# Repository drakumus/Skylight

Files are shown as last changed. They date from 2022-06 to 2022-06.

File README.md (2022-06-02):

# About
This is Skylight, a numpad with two rotary encoders using ATMEGA32a-PU Microcontroller.

# Project Details
## case
`case` the files used to laser cut my case out of acrylic and stainless steel. SendCutSend was a responsive and friendly service I used with reasonable prices, so I'd recommend contacting them.
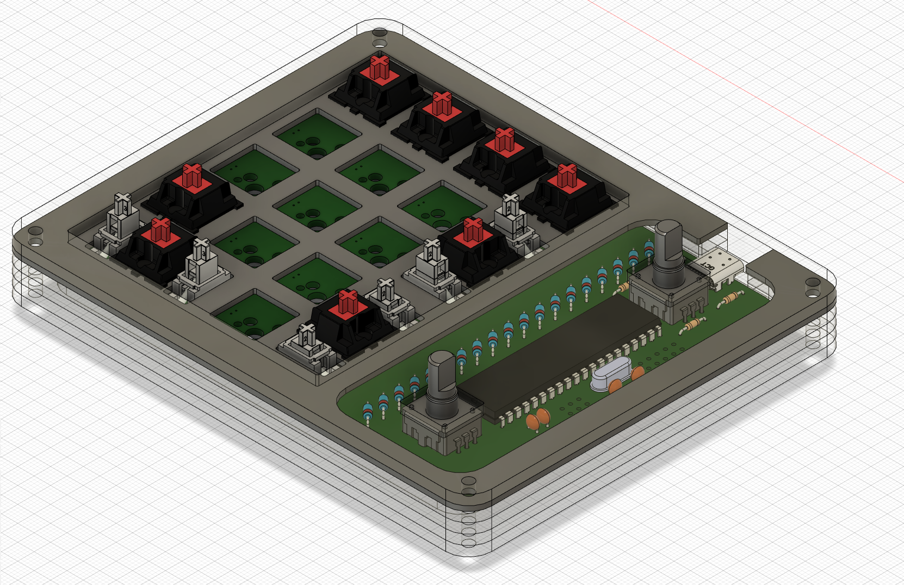
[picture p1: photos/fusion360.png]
case

### Files Required for Fabrication:
```
x1	bottom plate (closed).dxf 	- 3mm acrylic
x1	bottom plate (no usb).dxf 	- 3mm acrylic
x2	bottom plate.dxf		- 3mm acrylic
x1	plate.dxf			- stainless steel, ideal 1.5mm
x1	top plate v2.dxf		- 3mm acrylic
```
### Other Files
Other files can either be used for modeling i.e. the base.step which is a 3d render of the pcb for case design, or are previous iterations of files that I kept for future reference.
## USBaspLoader (bootloader)
ATMEGA32A-PU does not come with native USB support. A bootloader with VUSB support must be flashed to let QMK Toolbox recognize the device for flashing via USBasp. This is achieved with USBaspLoader.
I've included my confuration of the loader with instructions to use below.

**NOTE:** Flashing on windows requires avrdude. The sourceforge version of Avrdude that I will not link to **DELETES YOUR PATH ENVIRONMENT VARIABLE**. I did this twice on two different installs of windows before figuring it out. I hope you find a better way to install. You may have better luck with choco package manager for windows but the current version on there is 6.3 which requires custom drivers you must place manually in your system32 folder. The other option is WSL however I believe there are still limitations for that to see COM ports. I hope the future has a more dev friendly approach.
### Requirements
 - ISP (I repurposed a Pro Micro to do this, [see qmk's guide](https://github.com/qmk/qmk_firmware/blob/master/docs/isp_flashing_guide.md))
 - Avrdude
 - Git Bash (other WSL consoles probably work)
### Loading the Bootloader
1. Open [QMK Toolbox](https://github.com/qmk/qmk_toolbox/releases)
2. Check what COM port your ISP is plugged into (i.e. COM3)
3. Edit Makefile.inc (line 41) in the USBaspLoader folder with the correct COM port and the isp specified in the QMK guide above.
		i.e. `PROGRAMMER = -c avrisp -P COM3`
4. `cd` into my version of USBaspLoader with git bashs
5. Use git bash (has make tools we need) to execute:
  	1. make firmware
	2. avrdude -c avrisp -p m32 -P COM6 -v 
		- make sure the device number is not 0x00000, if it is double check the pin configuration on your ISP
	3. avrdude -c avrisp -p m32 -P COM6 -v -u -U lfuse:w:0x1F:m
	4. avrdude -c avrisp -p m32 -P COM6 -v -u -U hfuse:w:0xC0:m
	5. make flash
	6. avrdude -c avrisp -p m32 -P COM6 -U flash:r:-:i
		- this just reads the flash memory space to make sure the bits were set.

Congrats you now have a bootloader installed. You're now ready to flash your first firmware.
## firmware
**NOTE:** Do not attempt to flash the hex from qmk_firmware until after a bootloader has been flashed (found in USBaspLoader).

This folder contains the qmk firmware flashed to the board. Note that I flash the via supported kecap set.
If you want to play with this dump this folder into the keyboard folder in the qmk_firmware repository.
### Example build:
Open QMK MYSYS and run `qmk compile -kb zoci/skylight -km via` after dropping the zoci folder into the qmk_firmware/keyboard folder.
### Flashing the Board
1. In order to flash the two 2.54mm female "jumper" pins towards the right, top side of the board must be connected together. You can do this with tweezers or a wire.
2. Plug in the board via USB-C port on the device to USB-A on your computer.
3. QMK Toolbox should now detect the device (if the bootloader has been flashed previously)
4. Select the `zoci_skylight_via.hex` file in the firmware folder and click Flash.
5. Once it says flash complete disconnect the board from the computer then remove the connection between the two jumper pins.
6. Plug the board back into the computer.

You now have a functioning PCB!
### Via Support
> :warning: **Only use static RGB**: other color modes will cause the board to crash repeatedly forcing a reflash! This is likely because the microcontroller is too slow to continuously write rgb data.

In order for via to work with this board you must:
1. Go to the `SETTINGS` tab and toggle the "Show Design tab" to on.
2. Go to the `DESIGN` tab and select "LOAD" then open the via.json: `./firmware/zoci/skylight_s2/via.json`
3. Go to the `CONFIGURE` tab.
4. You may have to unplug and replug the board for it to show up. In general it is recommended to launch via then plug in the board.

You now can modify the button controls in via instead of building your own qmk hex!
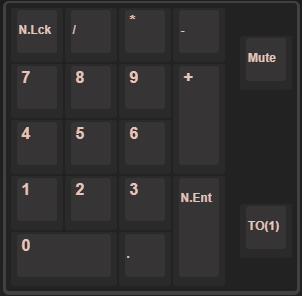
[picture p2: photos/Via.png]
Via

## kicad files
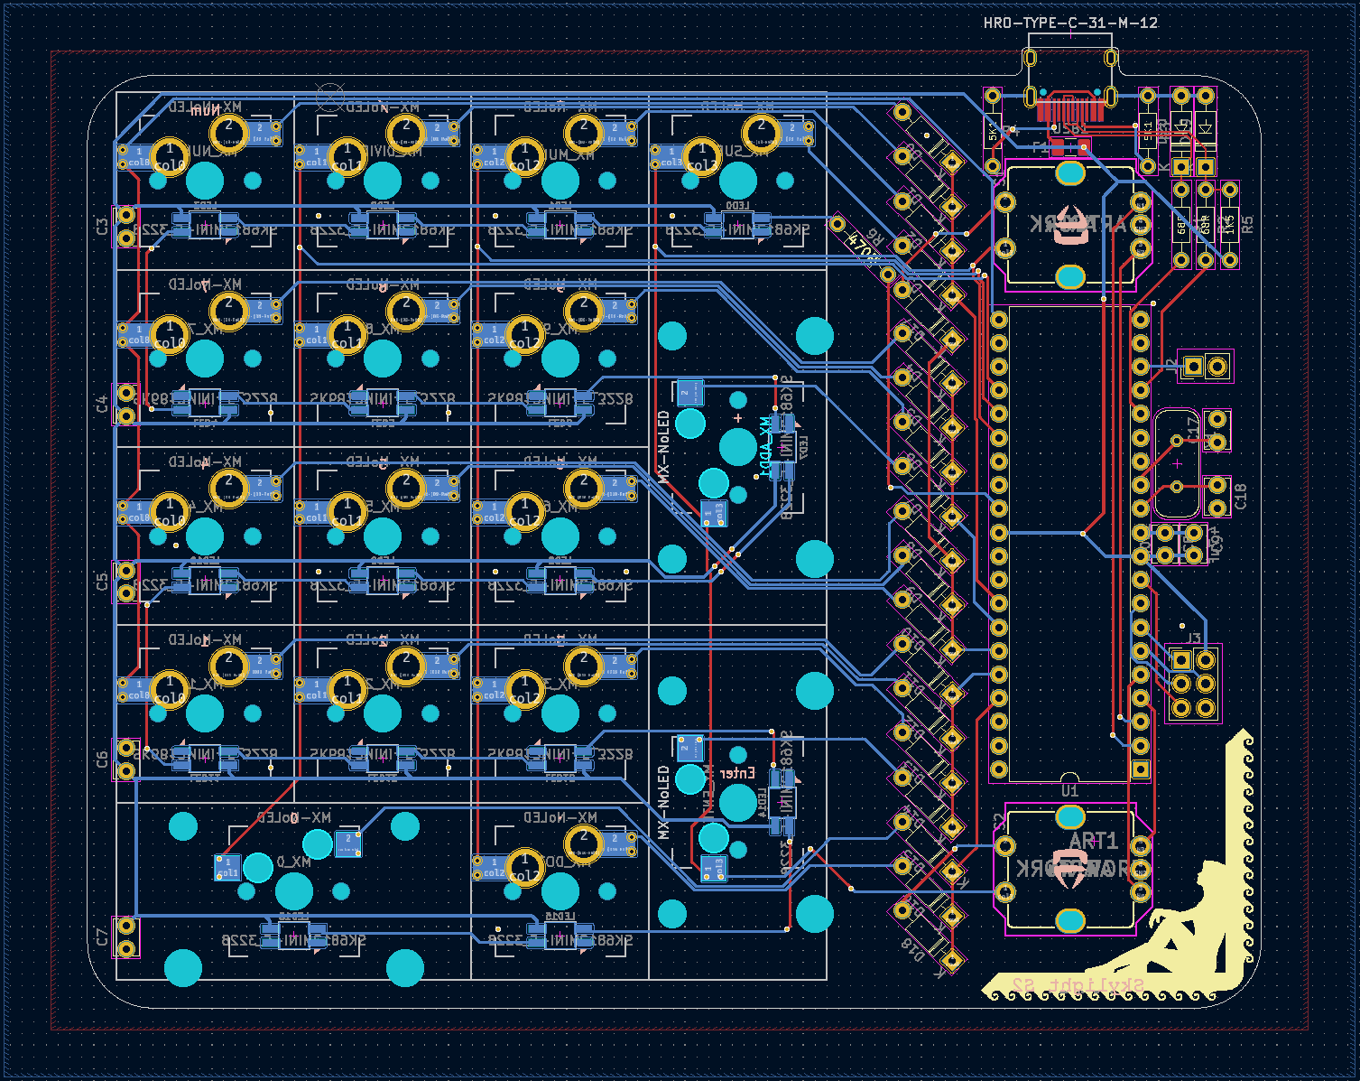
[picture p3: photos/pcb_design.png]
pcb

This folder contains the kicad project and its dependancies.
**Note:** You must clone recursively to get the submodule requirements for the kicad dependencies to load properly.
### Files Required for Fabrication
```
./Fabrication Files/plots final.zip
```

You can upload this file to a site like JLCPCB for fabrication.
### BOM
TODO

# Images

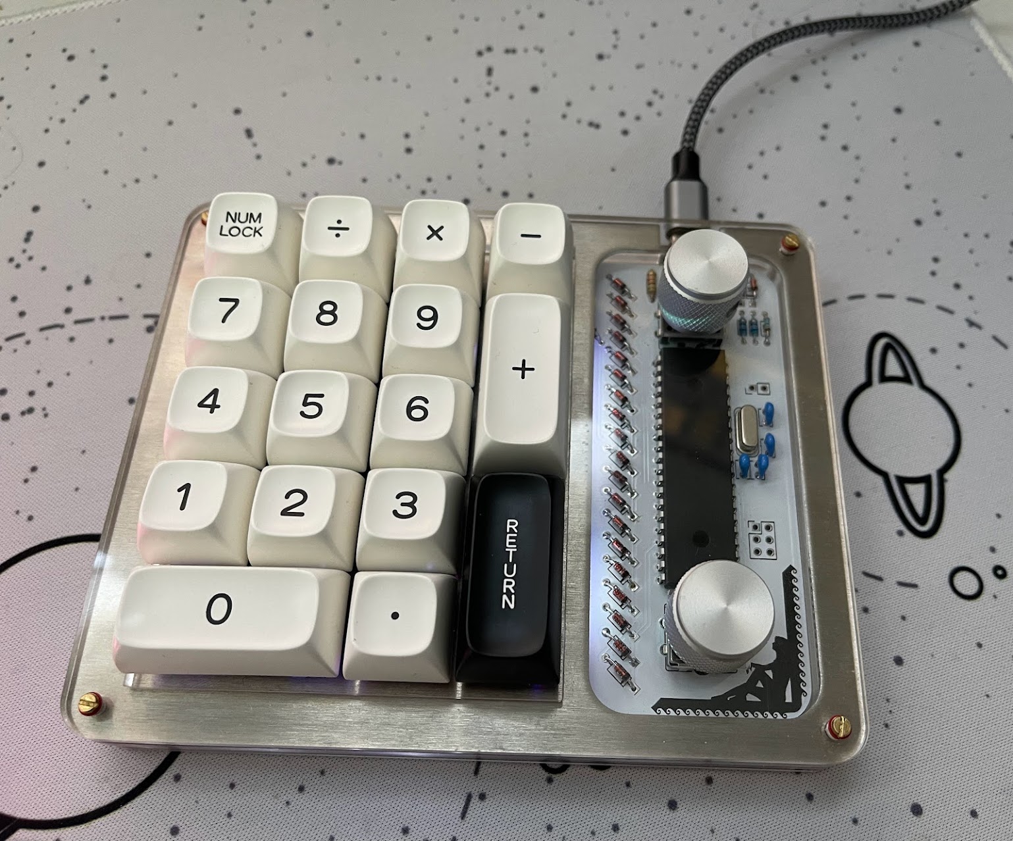
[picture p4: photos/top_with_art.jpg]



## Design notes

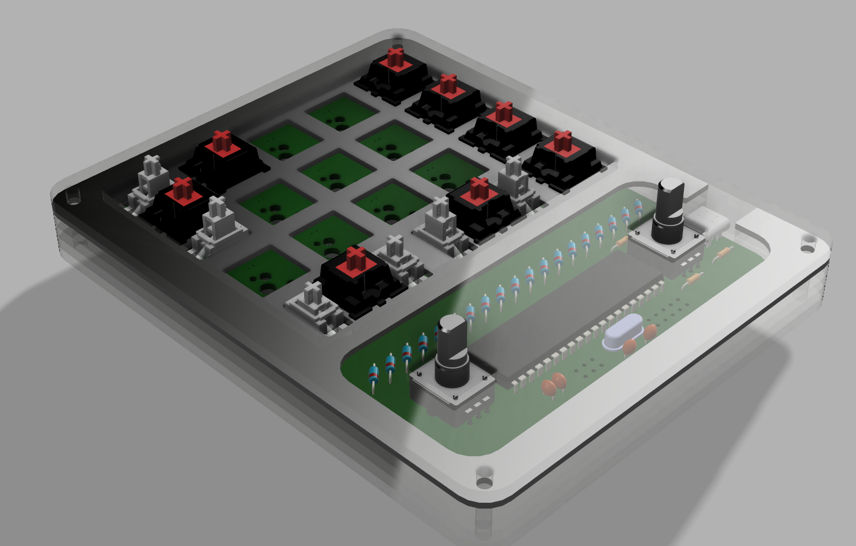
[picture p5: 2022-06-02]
photos/render.png

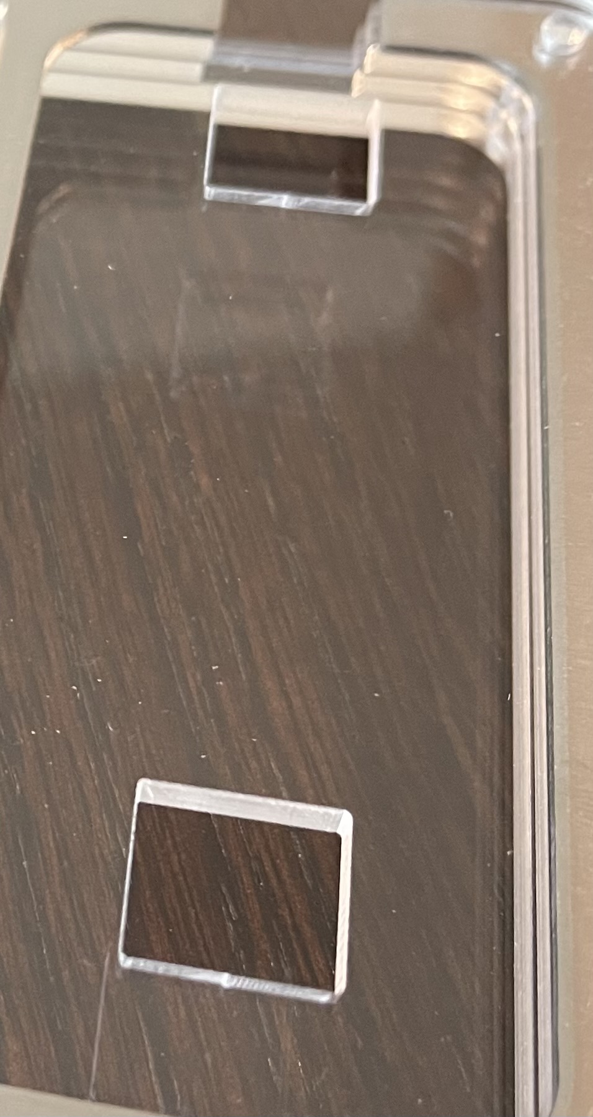
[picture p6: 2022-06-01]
case/bump.jpg

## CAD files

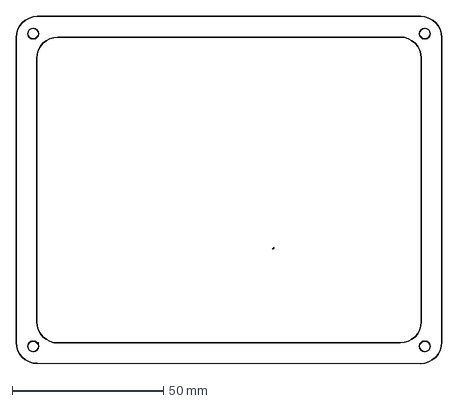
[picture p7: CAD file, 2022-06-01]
case/bottom plate (no usb).dxf
140.6 x 114.6 mm

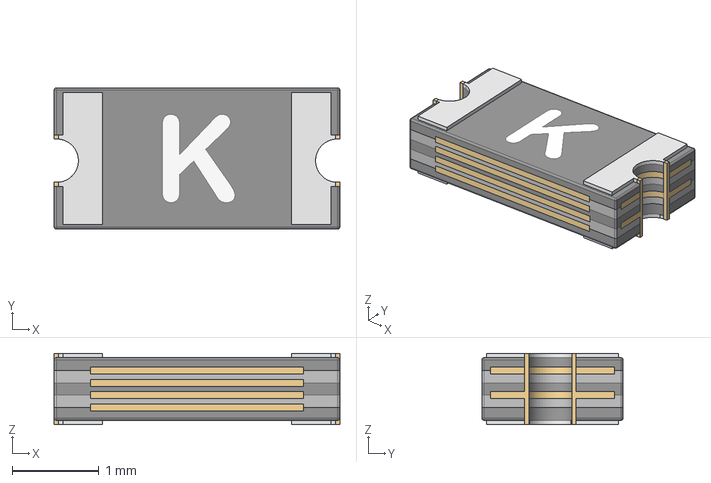
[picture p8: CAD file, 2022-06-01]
kicad files/components/smd-1206-fuse-littelfuse-1206l150thwr-1.snapshot.2/Fuse Littelfuse 1206L150THWR.stp
3.30 x 1.63 x 0.825 mm

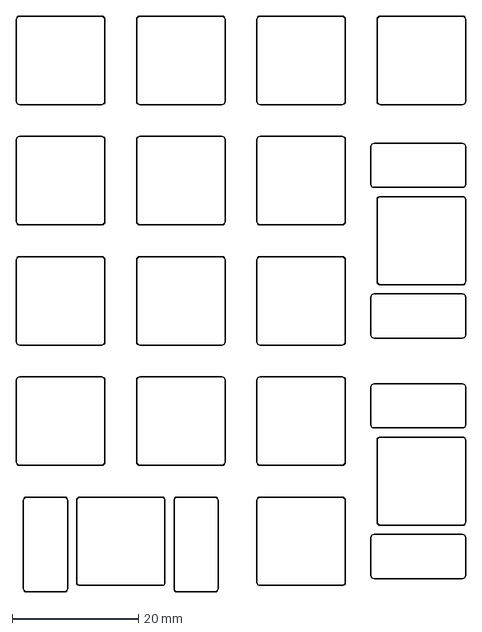
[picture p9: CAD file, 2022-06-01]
case/kbplate.dxf
71.1 x 91.2 mm

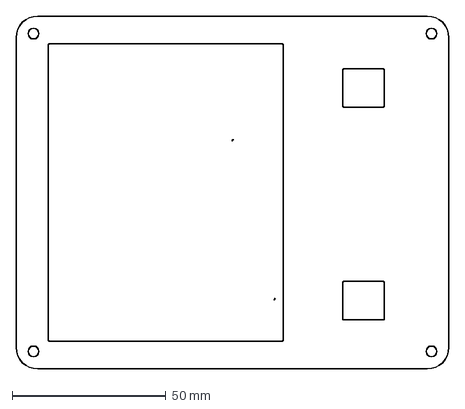
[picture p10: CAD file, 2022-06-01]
case/top plate.dxf
140.6 x 114.6 mm

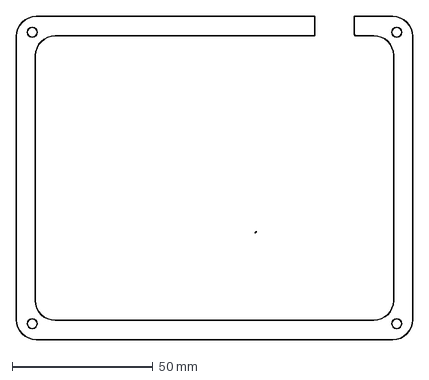
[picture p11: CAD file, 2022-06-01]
case/bottom plate.dxf
140.6 x 114.6 mm

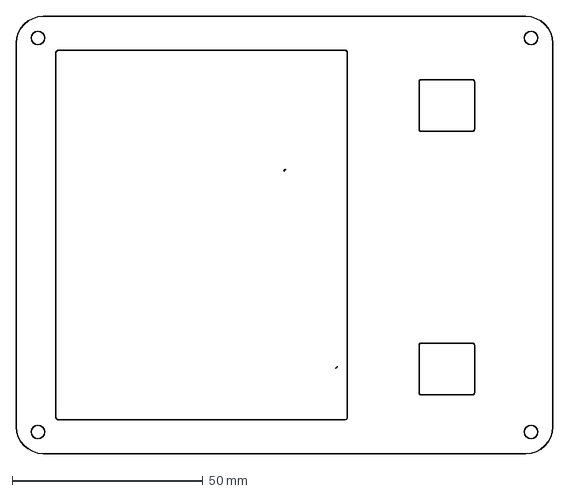
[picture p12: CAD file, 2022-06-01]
case/top plate v2.dxf
140.6 x 114.6 mm

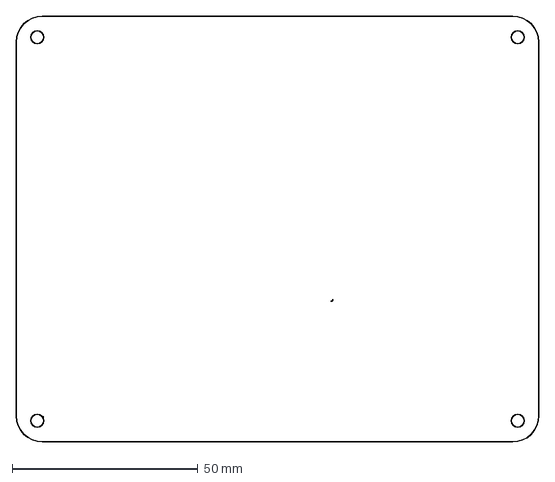
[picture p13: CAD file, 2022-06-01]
case/bottom plate (closed).dxf
140.6 x 114.6 mm

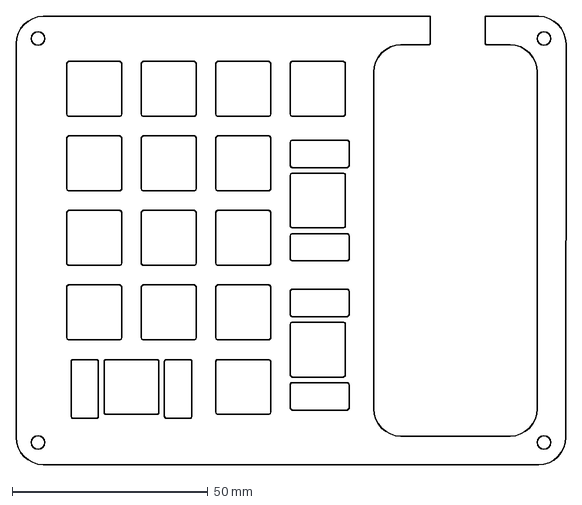
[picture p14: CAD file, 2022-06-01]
case/plate.dxf
140.6 x 114.6 mm

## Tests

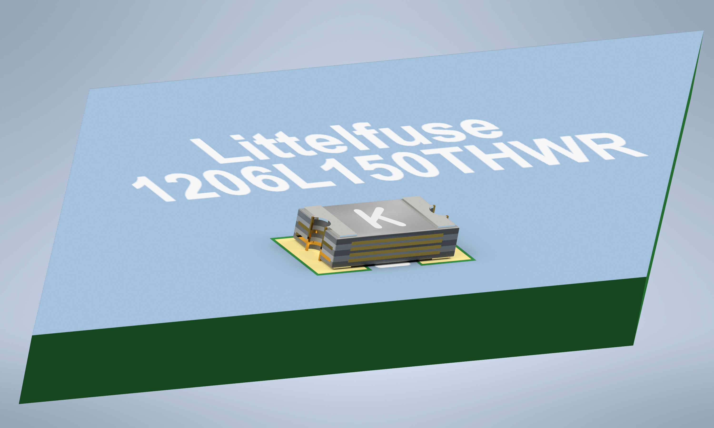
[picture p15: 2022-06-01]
kicad files/components/smd-1206-fuse-littelfuse-1206l150thwr-1.snapshot.2/Test.png

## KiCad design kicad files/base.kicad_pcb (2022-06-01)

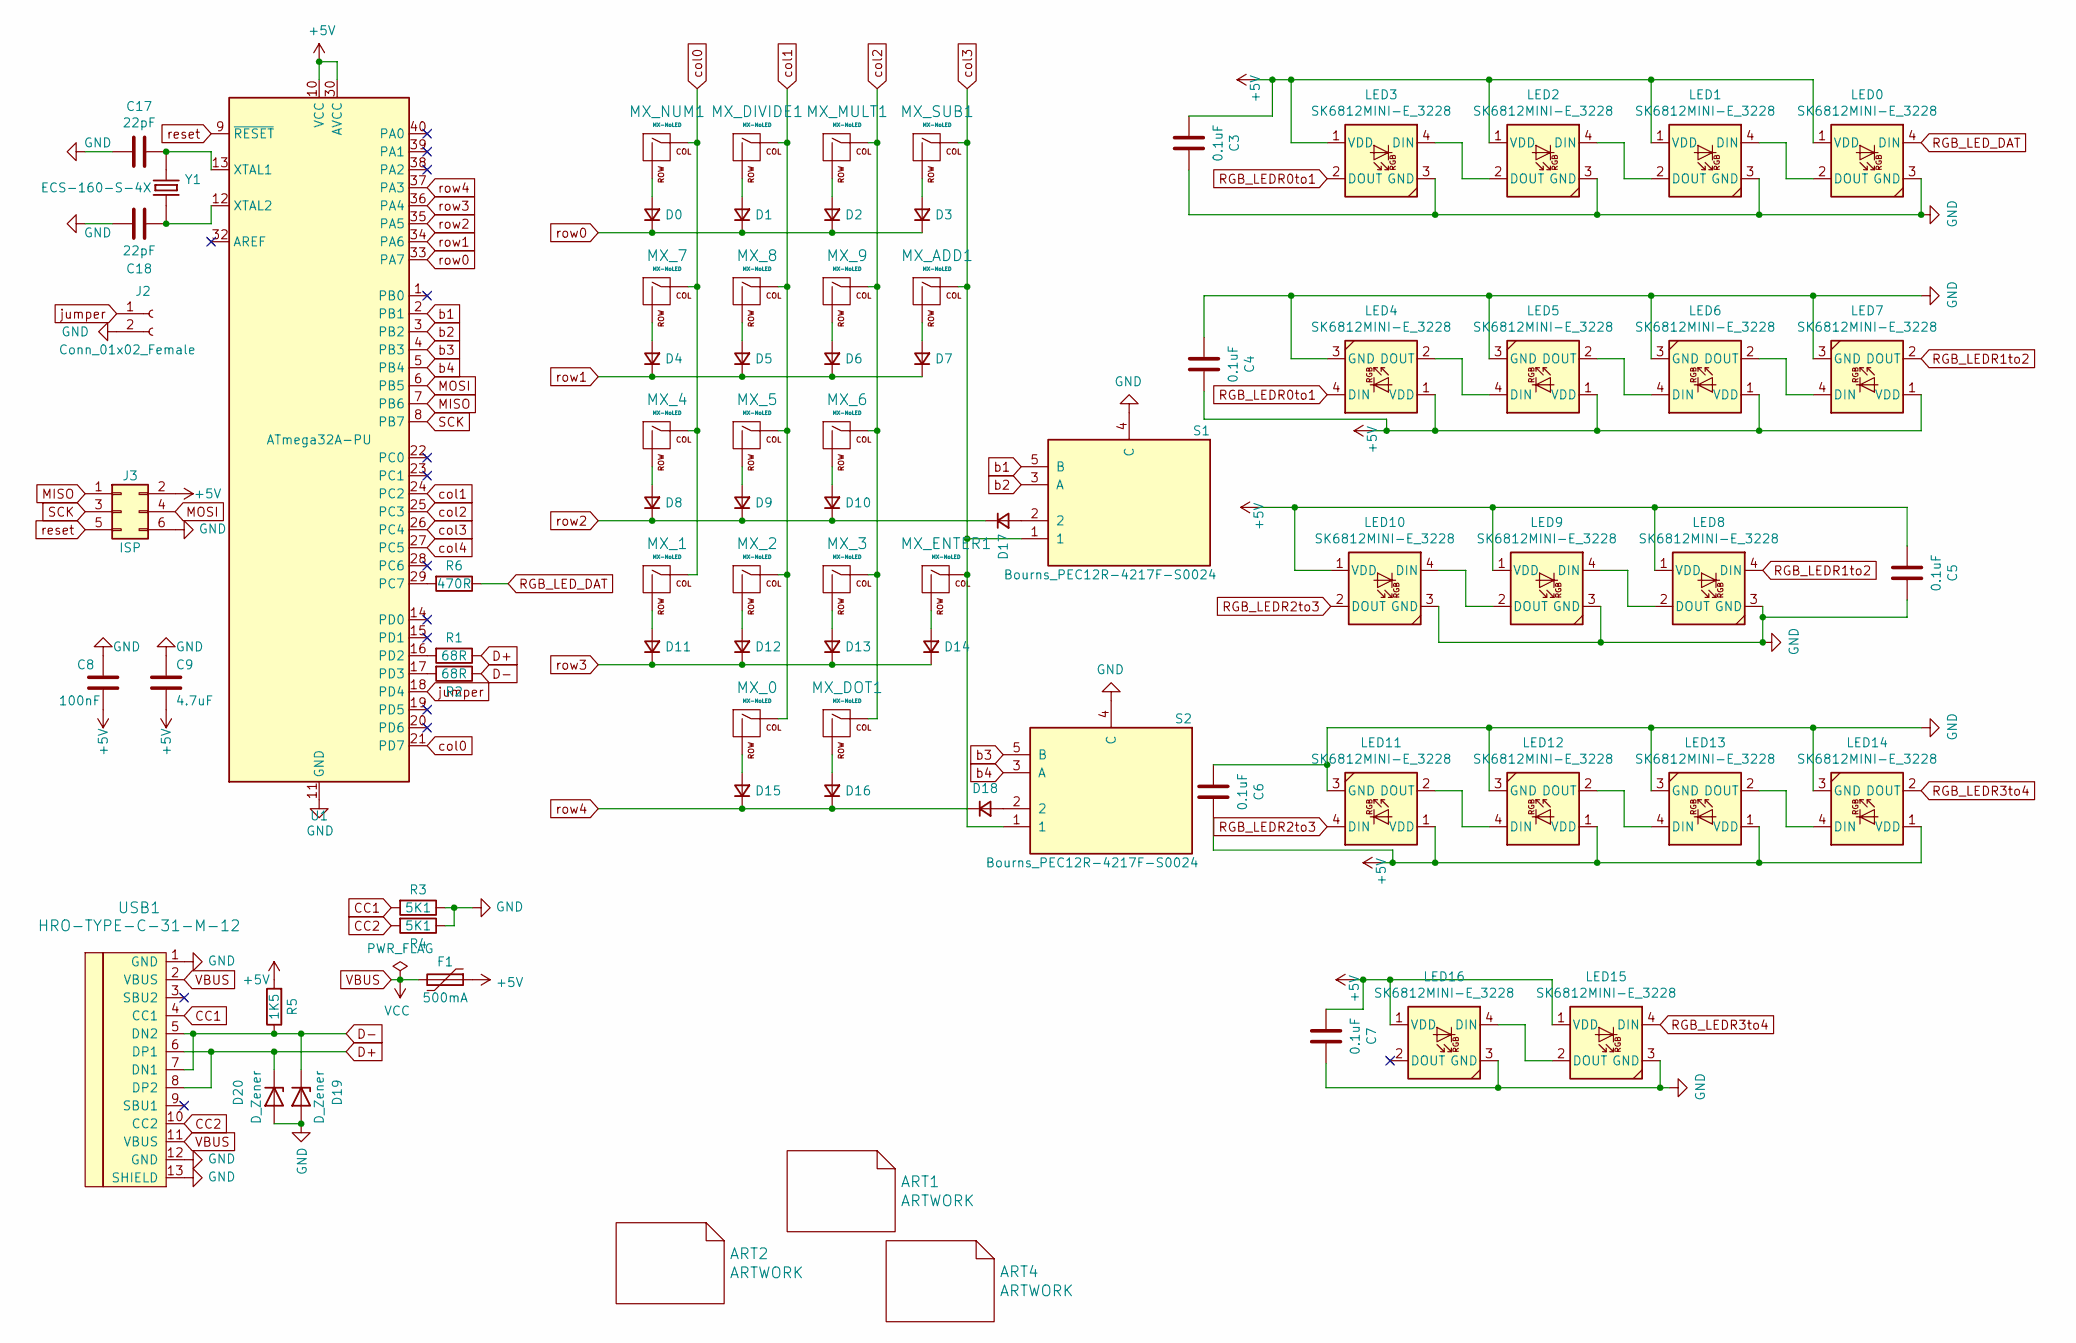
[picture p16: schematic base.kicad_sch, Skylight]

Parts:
ART1: ARTWORK; border and silhouette
ART2: ARTWORK; name
ART4: ARTWORK; avenda
C3, C4, C5, C6, C7: 0.1uF; C_Disc_D3.8mm_W2.6mm_P2.50mm
C8: 100nF; C_Disc_D3.8mm_W2.6mm_P2.50mm
C9: 4.7uF; C_Disc_D3.8mm_W2.6mm_P2.50mm
C17, C18: 22pF; C_Disc_D3.8mm_W2.6mm_P2.50mm
D0, D1, D2, D3, D4, D5, D6, D7, D8, D9, D10, D11, D12, D13, D14, D15, D16, D17, D18: D_Small; D_DO-35_SOD27_P7.62mm_Horizontal
D19, D20: D_Zener; D_DO-35_SOD27_P7.62mm_Horizontal
F1: 500mA; Fuse_1206_3216Metric
J2: Conn_01x02_Female; PinHeader_1x02_P2.54mm_Vertical
J3: ISP; PinHeader_2x03_P2.54mm_Vertical
LED0, LED1, LED2, LED3, LED4, LED5, LED6, LED7, LED8, LED9, LED10, LED11, LED12, LED13, LED14, LED15, LED16: SK6812MINI-E_3228; SK6812-MINI-E
MX_0: MX-NoLED; MXOnly-2U-Hotswap
MX_1, MX_2, MX_3, MX_4, MX_5, MX_6, MX_7, MX_8, MX_9: MX-NoLED; MXOnly-1U-Hotswap-Antishear
MX_ADD1: MX-NoLED; MXOnly-2U-Hotswap
MX_DIVIDE1: MX-NoLED; MXOnly-1U-Hotswap-Antishear
MX_DOT1: MX-NoLED; MXOnly-1U-Hotswap-Antishear
MX_ENTER1: MX-NoLED; MXOnly-2U-Hotswap
MX_MULT1: MX-NoLED; MXOnly-1U-Hotswap-Antishear
MX_NUM1: MX-NoLED; MXOnly-1U-Hotswap-Antishear
MX_SUB1: MX-NoLED; MXOnly-1U-Hotswap-Antishear
R1, R2: 68R; R_Axial_DIN0204_L3.6mm_D1.6mm_P7.62mm_Horizontal
R3, R4: 5K1; R_Axial_DIN0204_L3.6mm_D1.6mm_P7.62mm_Horizontal
R5: 1K5; R_Axial_DIN0204_L3.6mm_D1.6mm_P7.62mm_Horizontal
R6: 470R; R_Axial_DIN0204_L3.6mm_D1.6mm_P7.62mm_Horizontal
S1, S2: Bourns_PEC12R-4217F-S0024; PEC12R-4xxF-Sxxxx
U1: ATmega32A-PU; DIP-40_W15.24mm
USB1: HRO-TYPE-C-31-M-12; HRO-TYPE-C-31-M-12-HandSoldering
Y1: ECS-160-S-4X; XTAL_ECS-160-S-4X

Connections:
+5V: C3.2, C4.1, C5.2, C6.1, C7.2, C8.2, C9.2, F1.1, J3.2, LED0.1 (VDD), LED1.1 (VDD), LED2.1 (VDD), LED3.1 (VDD), LED4.1 (VDD), LED5.1 (VDD), LED6.1 (VDD), LED7.1 (VDD), LED8.1 (VDD), LED9.1 (VDD), LED10.1 (VDD), LED11.1 (VDD), LED12.1 (VDD), LED13.1 (VDD), LED14.1 (VDD), LED15.1 (VDD), LED16.1 (VDD), R5.2, U1.10 (VCC), U1.30 (AVCC)
CC1: R3.2, USB1.4 (CC1)
CC2: R4.2, USB1.10 (CC2)
D+: D20.1 (K), R1.1, USB1.6 (DP1), USB1.8 (DP2)
D-: D19.1 (K), R2.1, R5.1, USB1.5 (DN2), USB1.7 (DN1)
GND: C3.1, C4.2, C5.1, C6.2, C7.1, C8.1, C9.1, C17.2, C18.2, D19.2 (A), D20.2 (A), J2.2, J3.6, LED0.3 (GND), LED1.3 (GND), LED2.3 (GND), LED3.3 (GND), LED4.3 (GND), LED5.3 (GND), LED6.3 (GND), LED7.3 (GND), LED8.3 (GND), LED9.3 (GND), LED10.3 (GND), LED11.3 (GND), LED12.3 (GND), LED13.3 (GND), LED14.3 (GND), LED15.3 (GND), LED16.3 (GND), R3.1, R4.1, S1.4 (C), S2.4 (C), U1.11 (GND), U1.31 (GND), USB1.1 (GND), USB1.12 (GND), USB1.13 (SHIELD)
MISO: J3.1, U1.7 (PB6)
MOSI: J3.4, U1.6 (PB5)
unnamed: C17.1, U1.13 (XTAL1), Y1.1
unnamed: C18.1, U1.12 (XTAL2), Y1.2
unnamed: D0.2 (A), MX_NUM1.2 (ROW)
unnamed: D1.2 (A), MX_DIVIDE1.2 (ROW)
unnamed: D2.2 (A), MX_MULT1.2 (ROW)
unnamed: D3.2 (A), MX_SUB1.2 (ROW)
unnamed: D4.2 (A), MX_7.2 (ROW)
unnamed: D5.2 (A), MX_8.2 (ROW)
unnamed: D6.2 (A), MX_9.2 (ROW)
unnamed: D7.2 (A), MX_ADD1.2 (ROW)
unnamed: D8.2 (A), MX_4.2 (ROW)
unnamed: D9.2 (A), MX_5.2 (ROW)
unnamed: D10.2 (A), MX_6.2 (ROW)
unnamed: D11.2 (A), MX_1.2 (ROW)
unnamed: D12.2 (A), MX_2.2 (ROW)
unnamed: D13.2 (A), MX_3.2 (ROW)
unnamed: D14.2 (A), MX_ENTER1.2 (ROW)
unnamed: D15.2 (A), MX_0.2 (ROW)
unnamed: D16.2 (A), MX_DOT1.2 (ROW)
unnamed: D17.2 (A), S1.2
unnamed: D18.2 (A), S2.2
unnamed: LED0.2 (DOUT), LED1.4 (DIN)
unnamed: LED1.2 (DOUT), LED2.4 (DIN)
unnamed: LED2.2 (DOUT), LED3.4 (DIN)
unnamed: LED4.2 (DOUT), LED5.4 (DIN)
unnamed: LED5.2 (DOUT), LED6.4 (DIN)
unnamed: LED6.2 (DOUT), LED7.4 (DIN)
unnamed: LED8.2 (DOUT), LED9.4 (DIN)
unnamed: LED9.2 (DOUT), LED10.4 (DIN)
unnamed: LED11.2 (DOUT), LED12.4 (DIN)
unnamed: LED12.2 (DOUT), LED13.4 (DIN)
unnamed: LED13.2 (DOUT), LED14.4 (DIN)
unnamed: LED15.2 (DOUT), LED16.4 (DIN)
unnamed: R1.2, U1.16 (PD2)
unnamed: R2.2, U1.17 (PD3)
unnamed: R6.2, U1.29 (PC7)
RGB_LEDR0to1: LED3.2 (DOUT), LED4.4 (DIN)
RGB_LEDR1to2: LED7.2 (DOUT), LED8.4 (DIN)
RGB_LEDR2to3: LED10.2 (DOUT), LED11.4 (DIN)
RGB_LEDR3to4: LED14.2 (DOUT), LED15.4 (DIN)
RGB_LED_DAT: LED0.4 (DIN), R6.1
SCK: J3.3, U1.8 (PB7)
VBUS: F1.2, USB1.2 (VBUS), USB1.11 (VBUS)
b1: S1.5 (B), U1.2 (PB1)
b2: S1.3 (A), U1.3 (PB2)
b3: S2.5 (B), U1.4 (PB3)
b4: S2.3 (A), U1.5 (PB4)
col0: MX_1.1 (COL), MX_4.1 (COL), MX_7.1 (COL), MX_NUM1.1 (COL), U1.21 (PD7)
col1: MX_0.1 (COL), MX_2.1 (COL), MX_5.1 (COL), MX_8.1 (COL), MX_DIVIDE1.1 (COL), U1.24 (PC2)
col2: MX_3.1 (COL), MX_6.1 (COL), MX_9.1 (COL), MX_DOT1.1 (COL), MX_MULT1.1 (COL), U1.25 (PC3)
col3: MX_ADD1.1 (COL), MX_ENTER1.1 (COL), MX_SUB1.1 (COL), S1.1, S2.1, U1.26 (PC4)
col4: U1.27 (PC5)
jumper: J2.1, U1.18 (PD4)
reset: J3.5, U1.9 (~RESET)
row0: D0.1 (K), D1.1 (K), D2.1 (K), D3.1 (K), U1.33 (PA7)
row1: D4.1 (K), D5.1 (K), D6.1 (K), D7.1 (K), U1.34 (PA6)
row2: D8.1 (K), D9.1 (K), D10.1 (K), D17.1 (K), U1.35 (PA5)
row3: D11.1 (K), D12.1 (K), D13.1 (K), D14.1 (K), U1.36 (PA4)
row4: D15.1 (K), D16.1 (K), D18.1 (K), U1.37 (PA3)

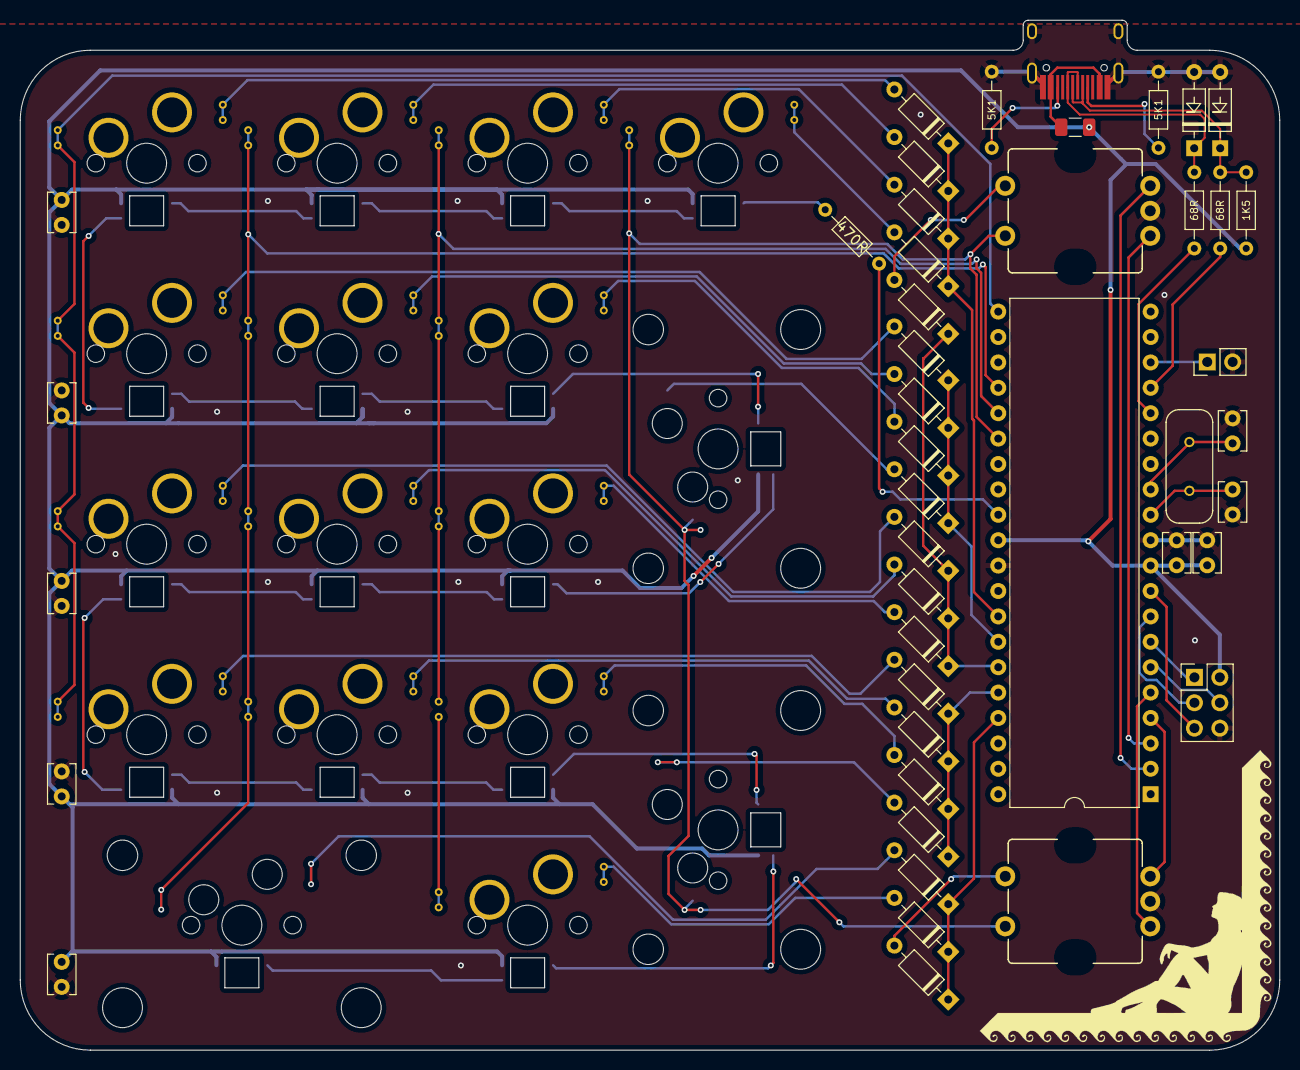
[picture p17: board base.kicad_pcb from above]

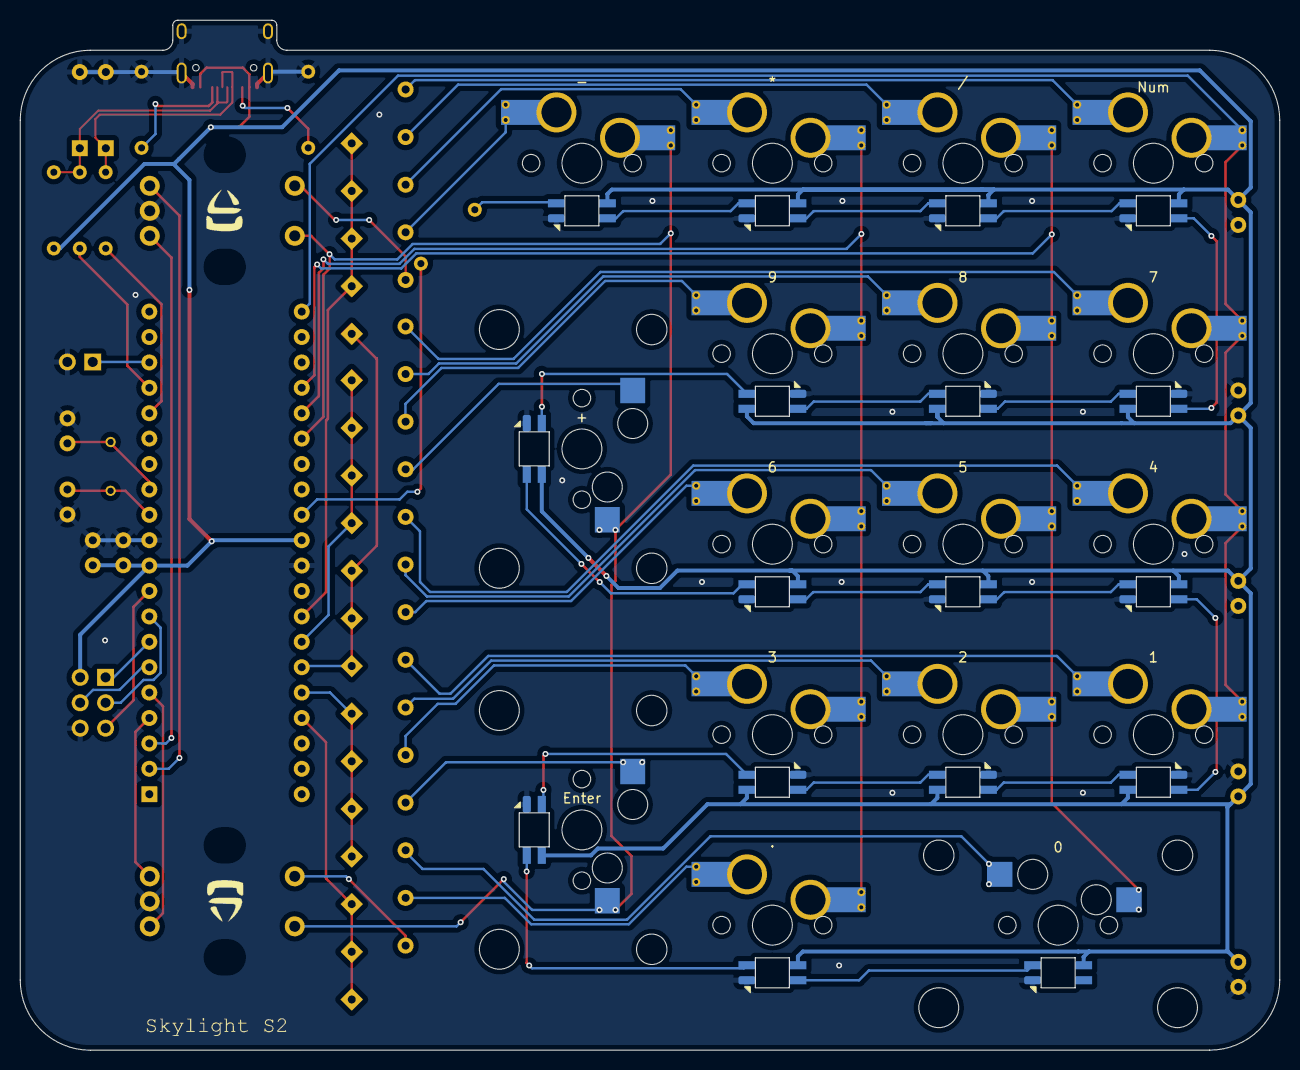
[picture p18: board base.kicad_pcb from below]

Board: 2 copper layers, 126.0 x 103.0 mm, 82 parts (20 on the bottom side), 66 nets.

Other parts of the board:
ART4#2: ARTWORK; avenda

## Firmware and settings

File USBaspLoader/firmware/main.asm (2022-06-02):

main.elf:     file format elf32-avr

SYMBOL TABLE:
00007000 l    d  .text	00000000 .text
00800060 l    d  .data	00000000 .data
00800066 l    d  .bss	00000000 .bss
0080009d l    d  .noinit	00000000 .noinit
00000000 l    d  .debug_aranges	00000000 .debug_aranges
00000000 l    d  .debug_pubnames	00000000 .debug_pubnames
00000000 l    d  .debug_info	00000000 .debug_info
00000000 l    d  .debug_abbrev	00000000 .debug_abbrev
00000000 l    d  .debug_line	00000000 .debug_line
00000000 l    d  .debug_frame	00000000 .debug_frame
00000000 l    d  .debug_str	00000000 .debug_str
00000000 l    d  .debug_loc	00000000 .debug_loc
00000000 l    d  .debug_macinfo	00000000 .debug_macinfo
00000000 l    d  .debug_ranges	00000000 .debug_ranges
00000000 l    df *ABS*	00000000 main.c
0000003f l       *ABS*	00000000 __SREG__
0000003e l       *ABS*	00000000 __SP_H__
0000003d l       *ABS*	00000000 __SP_L__
00000034 l       *ABS*	00000000 __CCP__
00000000 l       *ABS*	00000000 __tmp_reg__
00000001 l       *ABS*	00000000 __zero_reg__
000070e0 l       .text	00000000 __BOOTLOADERENTRY_FROMSOFTWARE__bootup_investigate_RAMEND_done5
000070de l       .text	00000000 __BOOTLOADERENTRY_FROMSOFTWARE__bootup_investigate_RAMEND_mismatch5
0080009d l     O .noinit	00000001 __BOOTLOADERENTRY_FROMSOFTWARE__bootup_RAMEND_doesmatch
0080009e l     O .noinit	00000001 __BOOTLOADERENTRY_FROMSOFTWARE__bootup_MCUCSR
0000736e l     F .text	0000000c __DO_NOT_USE_DIRECTLY_mywait
00007370 l       .text	00000000 _mywait_sleeploop19
00800062 l     O .data	00000004 signatureBytes
0080006b l     O .bss	00000001 stayinloader
0080006a l     O .bss	00000001 usbMsgFlags
00800066 l     O .bss	00000004 replyBuffer.1814
0080006c l     O .bss	00000002 currentAddress
0080006e l     O .bss	00000001 bytesRemaining
0080006f l     O .bss	00000001 isLastPage
00800070 l     O .bss	00000001 currentRequest
00800061 l     O .data	00000001 usbMsgLen
00800071 l     O .bss	00000002 nullVector
000070f8 l       .text	00000000 .do_copy_data_start
000070f4 l       .text	00000000 .do_copy_data_loop
00007108 l       .text	00000000 .do_clear_bss_start
00007106 l       .text	00000000 .do_clear_bss_loop
00007138 l       .text	00000000 usbCrcLoopEntry
00007126 l       .text	00000000 usbCrcByteLoop
0000712a l       .text	00000000 usbCrcBitLoop
00007134 l       .text	00000000 usbCrcNoXor
0000713c l       .text	00000000 usbCrcReady
0000714e l       .text	00000000 waitForJ
00007154 l       .text	00000000 waitForK
0000716e l       .text	00000000 foundK
00007280 l       .text	00000000 sofError
00007188 l       .text	00000000 haveTwoBitsK
00007216 l       .text	00000000 rxbit1
000071a4 l       .text	00000000 unstuff6
000071ec l       .text	00000000 didUnstuff6
000071b0 l       .text	00000000 unstuff7
000071fa l       .text	00000000 didUnstuff7
000071bc l       .text	00000000 unstuffEven
0000723a l       .text	00000000 se0
00007212 l       .text	00000000 didUnstuffE
000071cc l       .text	00000000 unstuffOdd
00007226 l       .text	00000000 didUnstuffO
000071dc l       .text	00000000 rxByteLoop
000071e8 l       .text	00000000 skipLeap
00007202 l       .text	00000000 rxBitLoop
00007232 l       .text	00000000 overflow
00007236 l       .text	00000000 ignorePacket
00007268 l       .text	00000000 storeTokenAndReturn
0000728a l       .text	00000000 handleData
000072b4 l       .text	00000000 handleIn
00007268 l       .text	00000000 handleSetupOrOut
0000726c l       .text	00000000 doReturn
000072e8 l       .text	00000000 sendNakAndReti
000072ec l       .text	00000000 sendAckAndReti
000072ee l       .text	00000000 sendCntAndReti
000072f6 l       .text	00000000 usbSendAndReti
000072d0 l       .text	00000000 bitstuffN
00007310 l       .text	00000000 didStuffN
000072dc l       .text	00000000 bitstuff6
0000731e l       .text	00000000 didStuff6
000072e4 l       .text	00000000 bitstuff7
0000732a l       .text	00000000 didStuff7
000072f0 l       .text	00000000 sendX3AndReti
00007304 l       .text	00000000 txByteLoop
00007306 l       .text	00000000 txBitLoop
00007352 l       .text	00000000 skipAddrAssign
00007362 l       .text	00000000 se0Delay
0000785e l       .text	00000000 __stop_program
00000000 l    df *ABS*	00000000 oddebug.c
0000003f l       *ABS*	00000000 __SREG__
0000003e l       *ABS*	00000000 __SP_H__
0000003d l       *ABS*	00000000 __SP_L__
00000034 l       *ABS*	00000000 __CCP__
00000000 l       *ABS*	00000000 __tmp_reg__
00000001 l       *ABS*	00000000 __zero_reg__
000070a0 g     O .text	00000012 usbDescriptorDevice
00007146 g     F .text	00000000 __vector_1
00800073 g     O .bss	0000000b usbTxBuf
00000000 g       *ABS*	00000000 nullVector
000070c4 g       .text	00000000 __trampolines_start
00007860 g       .text	00000000 _etext
00007072 g     O .text	00000004 usbDescriptorString0
00007112  w      .text	00000000 __vector_12
00007112 g       .text	00000000 __bad_interrupt
00007866 g       *ABS*	00000000 __data_load_end
00007112  w      .text	00000000 __vector_6
00007114 g       .text	00000000 usbCrc16
000070c4 g       .text	00000000 __trampolines_end
00007112  w      .text	00000000 __vector_3
000070d0 g     F .text	00000018 __BOOTLOADERENTRY_FROMSOFTWARE__bootup_investigate_RAMEND
00007860 g       *ABS*	00000000 __data_load_start
000070c4 g       .text	00000000 __dtors_end
0080009d g       .bss	00000000 __bss_end
00007054 g     O .text	0000001e bootloader__do_spm
00007112  w      .text	00000000 __vector_11
000070c4  w      .text	00000000 __init
00007112  w      .text	00000000 __vector_13
0000713e g       .text	00000000 usbCrc16Append
00007112  w      .text	00000000 __vector_17
00007112  w      .text	00000000 __vector_19
00007112  w      .text	00000000 __vector_7
00007832 g     F .text	00000010 __eerd_byte_m32
000070b2 g     O .text	00000012 usbDescriptorConfiguration
000070fe g       .text	00000000 __do_clear_bss
0080007e g     O .bss	00000001 usbDeviceAddr
00810000 g       .debug_aranges	00000000 __eeprom_end
0080007f g     O .bss	00000001 usbRxToken
00007000 g       .text	00000000 __vectors
00800066 g       .data	00000000 __data_end
00007076 g     O .text	0000001c usbDescriptorStringVendor
00800080 g     O .bss	00000001 usbInputBufOffset
00007000  w      .text	00000000 __vector_default
00007112  w      .text	00000000 __vector_5
00007844 g       .text	00000000 __eewr_r18_m32
000070c4 g       .text	00000000 __ctors_start
000070e8 g       .text	00000000 __do_copy_data
0000737a g     F .text	000000b0 usbFunctionSetup_USBASP_FUNC_TRANSMIT
00800066 g       .bss	00000000 __bss_start
00007424 g     F .text	0000041a main
00007112  w      .text	00000000 __vector_4
00800060 g     O .data	00000001 usbTxLen
00000000  w      *ABS*	00000000 __heap_end
00007112  w      .text	00000000 __vector_9
00007112  w      .text	00000000 __vector_2
00800081 g     O .bss	00000002 usbMsgPtr
00007112  w      .text	00000000 __vector_15
00800083 g     O .bss	00000001 usbRxLen
000070c4 g       .text	00000000 __dtors_start
000070c4 g       .text	00000000 __ctors_end
0000085f  w      *ABS*	00000000 __stack
00800084 g     O .bss	00000001 usbNewDeviceAddr
00800066 g       .data	00000000 _edata
0080009f g       .noinit	00000000 _end
00007112  w      .text	00000000 __vector_8
0000785c  w      .text	00000000 exit
00800085 g     O .bss	00000001 usbCurrentTok
00007092 g     O .text	0000000e usbDescriptorStringDevice
0000785c g       .text	00000000 _exit
00800086 g     O .bss	00000001 usbConfiguration
00007112  w      .text	00000000 __vector_14
00007842 g     F .text	0000001a __eewr_byte_m32
00007112  w      .text	00000000 __vector_10
00800087 g     O .bss	00000016 usbRxBuf
00007112  w      .text	00000000 __vector_16
00800060 g       .data	00000000 __data_start
00007112  w      .text	00000000 __vector_18
00007112  w      .text	00000000 __vector_20



Disassembly of section .text:

00007000 <__vectors>:
    7000:	61 c0       	rjmp	.+194    	; 0x70c4 <__ctors_end>
    7002:	00 00       	nop
    7004:	a0 c0       	rjmp	.+320    	; 0x7146 <__vector_1>
    7006:	00 00       	nop
    7008:	84 c0       	rjmp	.+264    	; 0x7112 <__bad_interrupt>
    700a:	00 00       	nop
    700c:	82 c0       	rjmp	.+260    	; 0x7112 <__bad_interrupt>
    700e:	00 00       	nop
    7010:	80 c0       	rjmp	.+256    	; 0x7112 <__bad_interrupt>
    7012:	00 00       	nop
    7014:	7e c0       	rjmp	.+252    	; 0x7112 <__bad_interrupt>
    7016:	00 00       	nop
    7018:	7c c0       	rjmp	.+248    	; 0x7112 <__bad_interrupt>
    701a:	00 00       	nop
    701c:	7a c0       	rjmp	.+244    	; 0x7112 <__bad_interrupt>
    701e:	00 00       	nop
    7020:	78 c0       	rjmp	.+240    	; 0x7112 <__bad_interrupt>
    7022:	00 00       	nop
    7024:	76 c0       	rjmp	.+236    	; 0x7112 <__bad_interrupt>
    7026:	00 00       	nop
    7028:	74 c0       	rjmp	.+232    	; 0x7112 <__bad_interrupt>
    702a:	00 00       	nop
    702c:	72 c0       	rjmp	.+228    	; 0x7112 <__bad_interrupt>
    702e:	00 00       	nop
    7030:	70 c0       	rjmp	.+224    	; 0x7112 <__bad_interrupt>
    7032:	00 00       	nop
    7034:	6e c0       	rjmp	.+220    	; 0x7112 <__bad_interrupt>
    7036:	00 00       	nop
    7038:	6c c0       	rjmp	.+216    	; 0x7112 <__bad_interrupt>
    703a:	00 00       	nop
    703c:	6a c0       	rjmp	.+212    	; 0x7112 <__bad_interrupt>
    703e:	00 00       	nop
    7040:	68 c0       	rjmp	.+208    	; 0x7112 <__bad_interrupt>
    7042:	00 00       	nop
    7044:	66 c0       	rjmp	.+204    	; 0x7112 <__bad_interrupt>
    7046:	00 00       	nop
    7048:	64 c0       	rjmp	.+200    	; 0x7112 <__bad_interrupt>
    704a:	00 00       	nop
    704c:	62 c0       	rjmp	.+196    	; 0x7112 <__bad_interrupt>
    704e:	00 00       	nop
    7050:	60 c0       	rjmp	.+192    	; 0x7112 <__bad_interrupt>
	...

00007054 <bootloader__do_spm>:
    7054:	ec 2d fd 2d b7 b6 b0 fc fd cf 27 bf e8 95 b7 b6     .-.-......'.....
    7064:	b0 fc fd cf 21 e1 b7 b6 b6 fc f4 cf 08 95           ....!.........

00007072 <usbDescriptorString0>:
    7072:	04 03 09 04                                         ....

00007076 <usbDescriptorStringVendor>:
    7076:	1c 03 77 00 77 00 77 00 2e 00 66 00 69 00 73 00     ..w.w.w...f.i.s.
    7086:	63 00 68 00 6c 00 2e 00 64 00 65 00                 c.h.l...d.e.

00007092 <usbDescriptorStringDevice>:
    7092:	0e 03 55 00 53 00 42 00 61 00 73 00 70 00           ..U.S.B.a.s.p.

000070a0 <usbDescriptorDevice>:
    70a0:	12 01 10 01 ff 00 00 08 c0 16 dc 05 02 01 01 02     ................
    70b0:	00 01                                               ..

000070b2 <usbDescriptorConfiguration>:
    70b2:	09 02 12 00 01 01 00 80 32 09 04 00 00 00 00 00     ........2.......
	...

000070c4 <__ctors_end>:
    70c4:	11 24       	eor	r1, r1
    70c6:	1f be       	out	0x3f, r1	; 63
    70c8:	cf e5       	ldi	r28, 0x5F	; 95
    70ca:	d8 e0       	ldi	r29, 0x08	; 8
    70cc:	de bf       	out	0x3e, r29	; 62
    70ce:	cd bf       	out	0x3d, r28	; 61

000070d0 <__BOOTLOADERENTRY_FROMSOFTWARE__bootup_investigate_RAMEND>:

/* ------------------------------------------------------------------------ */

#if (HAVE_BOOTLOADERENTRY_FROMSOFTWARE)
void __attribute__ ((section(".init3"),naked,used,no_instrument_function)) __BOOTLOADERENTRY_FROMSOFTWARE__bootup_investigate_RAMEND(void);
void __BOOTLOADERENTRY_FROMSOFTWARE__bootup_investigate_RAMEND(void) {
    70d0:	34 b7       	in	r19, 0x34	; 52
    70d2:	d8 e0       	ldi	r29, 0x08	; 8
    70d4:	ce e5       	ldi	r28, 0x5E	; 94
    70d6:	29 91       	ld	r18, Y+
    70d8:	28 33       	cpi	r18, 0x38	; 56
    70da:	29 91       	ld	r18, Y+
    70dc:	09 f0       	breq	.+2      	; 0x70e0 <__BOOTLOADERENTRY_FROMSOFTWARE__bootup_investigate_RAMEND_done5>

000070de <__BOOTLOADERENTRY_FROMSOFTWARE__bootup_investigate_RAMEND_mismatch5>:
    70de:	2f ef       	ldi	r18, 0xFF	; 255

000070e0 <__BOOTLOADERENTRY_FROMSOFTWARE__bootup_investigate_RAMEND_done5>:
    70e0:	20 93 9d 00 	sts	0x009D, r18
    70e4:	30 93 9e 00 	sts	0x009E, r19

000070e8 <__do_copy_data>:
    70e8:	10 e0       	ldi	r17, 0x00	; 0
    70ea:	a0 e6       	ldi	r26, 0x60	; 96
    70ec:	b0 e0       	ldi	r27, 0x00	; 0
    70ee:	e0 e6       	ldi	r30, 0x60	; 96
    70f0:	f8 e7       	ldi	r31, 0x78	; 120
    70f2:	02 c0       	rjmp	.+4      	; 0x70f8 <.do_copy_data_start>

000070f4 <.do_copy_data_loop>:
    70f4:	05 90       	lpm	r0, Z+
    70f6:	0d 92       	st	X+, r0

000070f8 <.do_copy_data_start>:
    70f8:	a6 36       	cpi	r26, 0x66	; 102
    70fa:	b1 07       	cpc	r27, r17
    70fc:	d9 f7       	brne	.-10     	; 0x70f4 <.do_copy_data_loop>

000070fe <__do_clear_bss>:
    70fe:	10 e0       	ldi	r17, 0x00	; 0
    7100:	a6 e6       	ldi	r26, 0x66	; 102
    7102:	b0 e0       	ldi	r27, 0x00	; 0
    7104:	01 c0       	rjmp	.+2      	; 0x7108 <.do_clear_bss_start>

00007106 <.do_clear_bss_loop>:
    7106:	1d 92       	st	X+, r1

00007108 <.do_clear_bss_start>:
    7108:	ad 39       	cpi	r26, 0x9D	; 157
    710a:	b1 07       	cpc	r27, r17
    710c:	e1 f7       	brne	.-8      	; 0x7106 <.do_clear_bss_loop>
    710e:	8a d1       	rcall	.+788    	; 0x7424 <main>
    7110:	a5 c3       	rjmp	.+1866   	; 0x785c <_exit>

00007112 <__bad_interrupt>:
    7112:	76 cf       	rjmp	.-276    	; 0x7000 <__vectors>

00007114 <usbCrc16>:
    7114:	a8 2f       	mov	r26, r24
    7116:	b9 2f       	mov	r27, r25
    7118:	80 e0       	ldi	r24, 0x00	; 0
    711a:	90 e0       	ldi	r25, 0x00	; 0
    711c:	41 e0       	ldi	r20, 0x01	; 1
    711e:	50 ea       	ldi	r21, 0xA0	; 160
    7120:	60 95       	com	r22
    7122:	30 e0       	ldi	r19, 0x00	; 0
    7124:	09 c0       	rjmp	.+18     	; 0x7138 <usbCrcLoopEntry>

00007126 <usbCrcByteLoop>:
    7126:	2d 91       	ld	r18, X+
    7128:	82 27       	eor	r24, r18

0000712a <usbCrcBitLoop>:
    712a:	97 95       	ror	r25
    712c:	87 95       	ror	r24
    712e:	10 f0       	brcs	.+4      	; 0x7134 <usbCrcNoXor>
    7130:	84 27       	eor	r24, r20
    7132:	95 27       	eor	r25, r21

00007134 <usbCrcNoXor>:
    7134:	30 5e       	subi	r19, 0xE0	; 224
    7136:	c8 f3       	brcs	.-14     	; 0x712a <usbCrcBitLoop>

00007138 <usbCrcLoopEntry>:
    7138:	6f 5f       	subi	r22, 0xFF	; 255
    713a:	a8 f3       	brcs	.-22     	; 0x7126 <usbCrcByteLoop>

0000713c <usbCrcReady>:
    713c:	08 95       	ret

0000713e <usbCrc16Append>:
    713e:	ea df       	rcall	.-44     	; 0x7114 <usbCrc16>
    7140:	8d 93       	st	X+, r24
    7142:	9d 93       	st	X+, r25
    7144:	08 95       	ret

00007146 <__vector_1>:
    7146:	cf 93       	push	r28
    7148:	cf b7       	in	r28, 0x3f	; 63
    714a:	cf 93       	push	r28
    714c:	df 93       	push	r29

0000714e <waitForJ>:
    714e:	c3 95       	inc	r28
    7150:	83 9b       	sbis	0x10, 3	; 16
    7152:	e9 f7       	brne	.-6      	; 0x714e <waitForJ>

00007154 <waitForK>:
    7154:	83 9b       	sbis	0x10, 3	; 16
    7156:	0b c0       	rjmp	.+22     	; 0x716e <foundK>
    7158:	83 9b       	sbis	0x10, 3	; 16
    715a:	09 c0       	rjmp	.+18     	; 0x716e <foundK>
    715c:	83 9b       	sbis	0x10, 3	; 16
    715e:	07 c0       	rjmp	.+14     	; 0x716e <foundK>
    7160:	83 9b       	sbis	0x10, 3	; 16
    7162:	05 c0       	rjmp	.+10     	; 0x716e <foundK>
    7164:	83 9b       	sbis	0x10, 3	; 16
    7166:	03 c0       	rjmp	.+6      	; 0x716e <foundK>
    7168:	83 9b       	sbis	0x10, 3	; 16
    716a:	01 c0       	rjmp	.+2      	; 0x716e <foundK>
    716c:	89 c0       	rjmp	.+274    	; 0x7280 <sofError>

0000716e <foundK>:
    716e:	6f 93       	push	r22
    7170:	c0 91 80 00 	lds	r28, 0x0080
    7174:	dd 27       	eor	r29, r29
    7176:	c9 57       	subi	r28, 0x79	; 121
    7178:	df 4f       	sbci	r29, 0xFF	; 255
    717a:	2f 93       	push	r18
    717c:	65 e5       	ldi	r22, 0x55	; 85
    717e:	83 9b       	sbis	0x10, 3	; 16
    7180:	03 c0       	rjmp	.+6      	; 0x7188 <haveTwoBitsK>
    7182:	2f 91       	pop	r18
    7184:	6f 91       	pop	r22
    7186:	e6 cf       	rjmp	.-52     	; 0x7154 <waitForK>

00007188 <haveTwoBitsK>:
    7188:	0f 93       	push	r16
    718a:	1f 93       	push	r17
    718c:	4f 93       	push	r20
    718e:	20 e0       	ldi	r18, 0x00	; 0
    7190:	40 e1       	ldi	r20, 0x10	; 16
    7192:	5f 93       	push	r21
    7194:	00 b3       	in	r16, 0x10	; 16
    7196:	0c 70       	andi	r16, 0x0C	; 12
    7198:	03 fb       	bst	r16, 3
    719a:	27 f9       	bld	r18, 7
    719c:	3f 93       	push	r19
    719e:	50 e0       	ldi	r21, 0x00	; 0
    71a0:	3b e0       	ldi	r19, 0x0B	; 11
    71a2:	39 c0       	rjmp	.+114    	; 0x7216 <rxbit1>

000071a4 <unstuff6>:
    71a4:	1c 70       	andi	r17, 0x0C	; 12
    71a6:	40 64       	ori	r20, 0x40	; 64
    71a8:	2f 77       	andi	r18, 0x7F	; 127
    71aa:	01 2f       	mov	r16, r17
    71ac:	5f 5f       	subi	r21, 0xFF	; 255
    71ae:	1e c0       	rjmp	.+60     	; 0x71ec <didUnstuff6>

000071b0 <unstuff7>:
    71b0:	40 68       	ori	r20, 0x80	; 128
    71b2:	10 b3       	in	r17, 0x10	; 16
    71b4:	1c 70       	andi	r17, 0x0C	; 12
    71b6:	2f 77       	andi	r18, 0x7F	; 127
    71b8:	52 50       	subi	r21, 0x02	; 2
    71ba:	1f c0       	rjmp	.+62     	; 0x71fa <didUnstuff7>

000071bc <unstuffEven>:
    71bc:	40 64       	ori	r20, 0x40	; 64
    71be:	00 b3       	in	r16, 0x10	; 16
    71c0:	2f 77       	andi	r18, 0x7F	; 127
    71c2:	0c 70       	andi	r16, 0x0C	; 12
    71c4:	d1 f1       	breq	.+116    	; 0x723a <se0>
    71c6:	5f 5f       	subi	r21, 0xFF	; 255
    71c8:	00 c0       	rjmp	.+0      	; 0x71ca <unstuffEven+0xe>
    71ca:	23 c0       	rjmp	.+70     	; 0x7212 <didUnstuffE>

000071cc <unstuffOdd>:
    71cc:	40 62       	ori	r20, 0x20	; 32
    71ce:	10 b3       	in	r17, 0x10	; 16
    71d0:	2f 77       	andi	r18, 0x7F	; 127
    71d2:	1c 70       	andi	r17, 0x0C	; 12
    71d4:	91 f1       	breq	.+100    	; 0x723a <se0>
    71d6:	5f 5f       	subi	r21, 0xFF	; 255
    71d8:	00 c0       	rjmp	.+0      	; 0x71da <unstuffOdd+0xe>
    71da:	25 c0       	rjmp	.+74     	; 0x7226 <didUnstuffO>

000071dc <rxByteLoop>:
    71dc:	0c 70       	andi	r16, 0x0C	; 12
    71de:	10 27       	eor	r17, r16
    71e0:	51 50       	subi	r21, 0x01	; 1
    71e2:	12 f4       	brpl	.+4      	; 0x71e8 <skipLeap>
    71e4:	5d 5f       	subi	r21, 0xFD	; 253
	...

000071e8 <skipLeap>:
    71e8:	11 50       	subi	r17, 0x01	; 1
    71ea:	27 95       	ror	r18

000071ec <didUnstuff6>:
    71ec:	2c 3f       	cpi	r18, 0xFC	; 252
    71ee:	10 b3       	in	r17, 0x10	; 16
    71f0:	c8 f6       	brcc	.-78     	; 0x71a4 <unstuff6>
    71f2:	1c 70       	andi	r17, 0x0C	; 12
    71f4:	01 27       	eor	r16, r17
    71f6:	01 50       	subi	r16, 0x01	; 1
    71f8:	27 95       	ror	r18

000071fa <didUnstuff7>:
    71fa:	2c 3f       	cpi	r18, 0xFC	; 252
    71fc:	c8 f6       	brcc	.-78     	; 0x71b0 <unstuff7>
    71fe:	42 27       	eor	r20, r18
    7200:	49 93       	st	Y+, r20

00007202 <rxBitLoop>:
    7202:	00 b3       	in	r16, 0x10	; 16
    7204:	0c 70       	andi	r16, 0x0C	; 12
    7206:	10 27       	eor	r17, r16
    7208:	4f 73       	andi	r20, 0x3F	; 63
    720a:	11 50       	subi	r17, 0x01	; 1
    720c:	27 95       	ror	r18
    720e:	2c 3f       	cpi	r18, 0xFC	; 252
    7210:	a8 f6       	brcc	.-86     	; 0x71bc <unstuffEven>

00007212 <didUnstuffE>:
    7212:	46 95       	lsr	r20
    7214:	46 95       	lsr	r20

00007216 <rxbit1>:
    7216:	10 b3       	in	r17, 0x10	; 16
    7218:	1c 70       	andi	r17, 0x0C	; 12
    721a:	79 f0       	breq	.+30     	; 0x723a <se0>
    721c:	01 27       	eor	r16, r17
    721e:	01 50       	subi	r16, 0x01	; 1
    7220:	27 95       	ror	r18
    7222:	2c 3f       	cpi	r18, 0xFC	; 252
    7224:	98 f6       	brcc	.-90     	; 0x71cc <unstuffOdd>

00007226 <didUnstuffO>:
    7226:	6b 5a       	subi	r22, 0xAB	; 171
    7228:	60 f3       	brcs	.-40     	; 0x7202 <rxBitLoop>
    722a:	31 50       	subi	r19, 0x01	; 1
    722c:	00 b3       	in	r16, 0x10	; 16
    722e:	b0 f6       	brcc	.-84     	; 0x71dc <rxByteLoop>
    7230:	00 c0       	rjmp	.+0      	; 0x7232 <overflow>

00007232 <overflow>:
    7232:	10 e4       	ldi	r17, 0x40	; 64
    7234:	1a bf       	out	0x3a, r17	; 58

00007236 <ignorePacket>:
    7236:	00 27       	eor	r16, r16
    7238:	17 c0       	rjmp	.+46     	; 0x7268 <handleSetupOrOut>

0000723a <se0>:
    723a:	3b 50       	subi	r19, 0x0B	; 11
    723c:	31 95       	neg	r19
    723e:	c3 1b       	sub	r28, r19
    7240:	d0 40       	sbci	r29, 0x00	; 0
    7242:	10 e4       	ldi	r17, 0x40	; 64
    7244:	1a bf       	out	0x3a, r17	; 58
    7246:	08 81       	ld	r16, Y
    7248:	03 3c       	cpi	r16, 0xC3	; 195
    724a:	f9 f0       	breq	.+62     	; 0x728a <handleData>
    724c:	0b 34       	cpi	r16, 0x4B	; 75
    724e:	e9 f0       	breq	.+58     	; 0x728a <handleData>
    7250:	20 91 7e 00 	lds	r18, 0x007E
    7254:	19 81       	ldd	r17, Y+1	; 0x01
    7256:	11 0f       	add	r17, r17
    7258:	12 13       	cpse	r17, r18
    725a:	ed cf       	rjmp	.-38     	; 0x7236 <ignorePacket>
    725c:	09 36       	cpi	r16, 0x69	; 105
    725e:	51 f1       	breq	.+84     	; 0x72b4 <handleIn>
    7260:	0d 32       	cpi	r16, 0x2D	; 45
    7262:	11 f0       	breq	.+4      	; 0x7268 <handleSetupOrOut>
    7264:	01 3e       	cpi	r16, 0xE1	; 225
    7266:	39 f7       	brne	.-50     	; 0x7236 <ignorePacket>

00007268 <handleSetupOrOut>:
    7268:	00 93 85 00 	sts	0x0085, r16

0000726c <doReturn>:
    726c:	3f 91       	pop	r19
    726e:	5f 91       	pop	r21
    7270:	4f 91       	pop	r20
    7272:	1f 91       	pop	r17
    7274:	0f 91       	pop	r16
    7276:	2f 91       	pop	r18
    7278:	6f 91       	pop	r22
    727a:	ca b7       	in	r28, 0x3a	; 58
    727c:	c6 fd       	sbrc	r28, 6
    727e:	67 cf       	rjmp	.-306    	; 0x714e <waitForJ>

00007280 <sofError>:
    7280:	df 91       	pop	r29
    7282:	cf 91       	pop	r28
    7284:	cf bf       	out	0x3f, r28	; 63
    7286:	cf 91       	pop	r28
    7288:	18 95       	reti
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

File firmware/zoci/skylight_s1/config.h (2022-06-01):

/*
Copyright 2021 RuckerMachine

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
You should have received a copy of the GNU General Public License
along with this program.  If not, see <http://www.gnu.org/licenses/>.
*/

#pragma once

#include "config_common.h"

/* USB Device descriptor parameter */
#define VENDOR_ID    0x8008  // random
#define PRODUCT_ID   0x0B1C  // random
#define DEVICE_VER   0x0001
#define MANUFACTURER Zoci
#define PRODUCT      skylight_s1

/* key matrix size */
#define MATRIX_ROWS 5
#define MATRIX_COLS 4

/*
 * Keyboard Matrix Assignments
 *
 * Change this to how you wired your keyboard
 * COLS: AVR pins used for columns, left to right
 * ROWS: AVR pins used for rows, top to bottom
 * DIODE_DIRECTION: COL2ROW = COL = Anode (+), ROW = Cathode (-, marked on diode)
 *                  ROW2COL = ROW = Anode (+), COL = Cathode (-, marked on diode)
 *
 */

#define MATRIX_ROW_PINS { A7, A6, A5, A4, A3  }
#define MATRIX_COL_PINS { D7, C2, C3, C4 }

#define UNUSED_PINS

/* COL2ROW, ROW2COL */
#define DIODE_DIRECTION COL2ROW

/* define encoder pins */
#define ENCODERS_PAD_A { B1, B3 }
#define ENCODERS_PAD_B { B2, B4 }

#define ENCODER_RESOLUTION 1

/*
 * Split Keyboard specific options, make sure you have 'SPLIT_KEYBOARD = yes' in your rules.mk, and define SOFT_SERIAL_PIN.
 *
 * #define SOFT_SERIAL_PIN D0  // or D1, D2, D3, E6
 */

//#define LED_NUM_LOCK_PIN B0
//#define LED_CAPS_LOCK_PIN B1
//#define LED_SCROLL_LOCK_PIN B2
//#define LED_COMPOSE_PIN B3
//#define LED_KANA_PIN B4

//#define BACKLIGHT_PIN B7
//#define BACKLIGHT_LEVELS 3
//#define BACKLIGHT_BREATHING


#define RGB_DI_PIN C7
#ifdef RGB_DI_PIN
#    define RGBLED_NUM 17
#    define RGBLIGHT_LED_MAP  { 3, 2, 1, 0, \
                                4, 5, 6, 7, \
                                10, 9, 8, \
                                11, 12, 13, 14, \
                                16, 15 }
#    define RGBLIGHT_HUE_STEP 8
#    define RGBLIGHT_SAT_STEP 8
#    define RGBLIGHT_VAL_STEP 8
#    define RGBLIGHT_LIMIT_VAL 255 /* The maximum brightness level */
#    define RGBLIGHT_SLEEP  /* If defined, the RGB lighting will be switched off when the host goes to sleep */
/*== all animations enable ==*/
//#    define RGBLIGHT_ANIMATIONS
/*== or choose animations ==*/
//#    define RGBLIGHT_EFFECT_BREATHING4
//#    define RGBLIGHT_EFFECT_RAINBOW_MOOD
//#    define RGBLIGHT_EFFECT_RAINBOW_SWIRL
//#    define RGBLIGHT_EFFECT_SNAKE
//#    define RGBLIGHT_EFFECT_KNIGHT
//#    define RGBLIGHT_EFFECT_CHRISTMAS
//#    define RGBLIGHT_EFFECT_STATIC_GRADIENT
#    define RGBLIGHT_EFFECT_RGB_TEST
//#    define RGBLIGHT_EFFECT_ALTERNATING
/*== customize breathing effect ==*/
/*==== (DEFAULT) use fixed table instead of exp() and sin() ====*/
//#    define RGBLIGHT_BREATHE_TABLE_SIZE 256      // 256(default) or 128 or 64
/*==== use exp() and sin() ====*/
//#    define RGBLIGHT_EFFECT_BREATHE_CENTER 1.85  // 1 to 2.7
//#    define RGBLIGHT_EFFECT_BREATHE_MAX    255   // 0 to 255

#endif

/* Debounce reduces chatter (unintended double-presses) - set 0 if debouncing is not needed */
#define DEBOUNCE 5

/* define if matrix has ghost (lacks anti-ghosting diodes) */
//#define MATRIX_HAS_GHOST

/* Mechanical locking support. Use KC_LCAP, KC_LNUM or KC_LSCR instead in keymap */
//#define LOCKING_SUPPORT_ENABLE
/* Locking resynchronize hack */
//#define LOCKING_RESYNC_ENABLE

/* If defined, GRAVE_ESC will always act as ESC when CTRL is held.
 * This is useful for the Windows task manager shortcut (ctrl+shift+esc).
 */
//#define GRAVE_ESC_CTRL_OVERRIDE

/*
 * Force NKRO
 *
 * Force NKRO (nKey Rollover) to be enabled by default, regardless of the saved
 * state in the bootmagic EEPROM settings. (Note that NKRO must be enabled in the
 * makefile for this to work.)
 *
 * If forced on, NKRO can be disabled via magic key (default = LShift+RShift+N)
 * until the next keyboard reset.
 *
 * NKRO may prevent your keystrokes from being detected in the BIOS, but it is
 * fully operational during normal computer usage.
 *
 * For a less heavy-handed approach, enable NKRO via magic key (LShift+RShift+N)
 * or via bootmagic (hold SPACE+N while plugging in the keyboard). Once set by
 * bootmagic, NKRO mode will always be enabled until it is toggled again during a
 * power-up.
 *
 */
//#define FORCE_NKRO

/*
 * Feature disable options
 *  These options are also useful to firmware size reduction.
 */

/* disable debug print */
//#define NO_DEBUG

/* disable print */
//#define NO_PRINT

/* disable action features */
//#define NO_ACTION_LAYER
//#define NO_ACTION_TAPPING
//#define NO_ACTION_ONESHOT

/* Bootmagic Lite key configuration */
//#define BOOTMAGIC_LITE_ROW 0
//#define BOOTMAGIC_LITE_COLUMN 0

// VUSB D- port
#define USB_CFG_DMINUS_BIT 3
// VUSB D+ port
#define USB_CFG_DPLUS_BIT 2

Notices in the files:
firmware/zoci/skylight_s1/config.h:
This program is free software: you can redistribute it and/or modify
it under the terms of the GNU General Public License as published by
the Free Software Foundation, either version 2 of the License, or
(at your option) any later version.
